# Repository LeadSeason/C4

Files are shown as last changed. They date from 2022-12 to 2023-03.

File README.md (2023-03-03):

<h1 align="center">Connect4 Robot</h1>
<p align="center">Connect 4 robot to play against</p>
<p align="center">
  
</p>

## About
Made with help from [Toni Lipponen](https://github.com/ToniLipponen),
or how I like to call him [Tonnikala](https://github.com/ToniLipponen).  

<p  align="center">
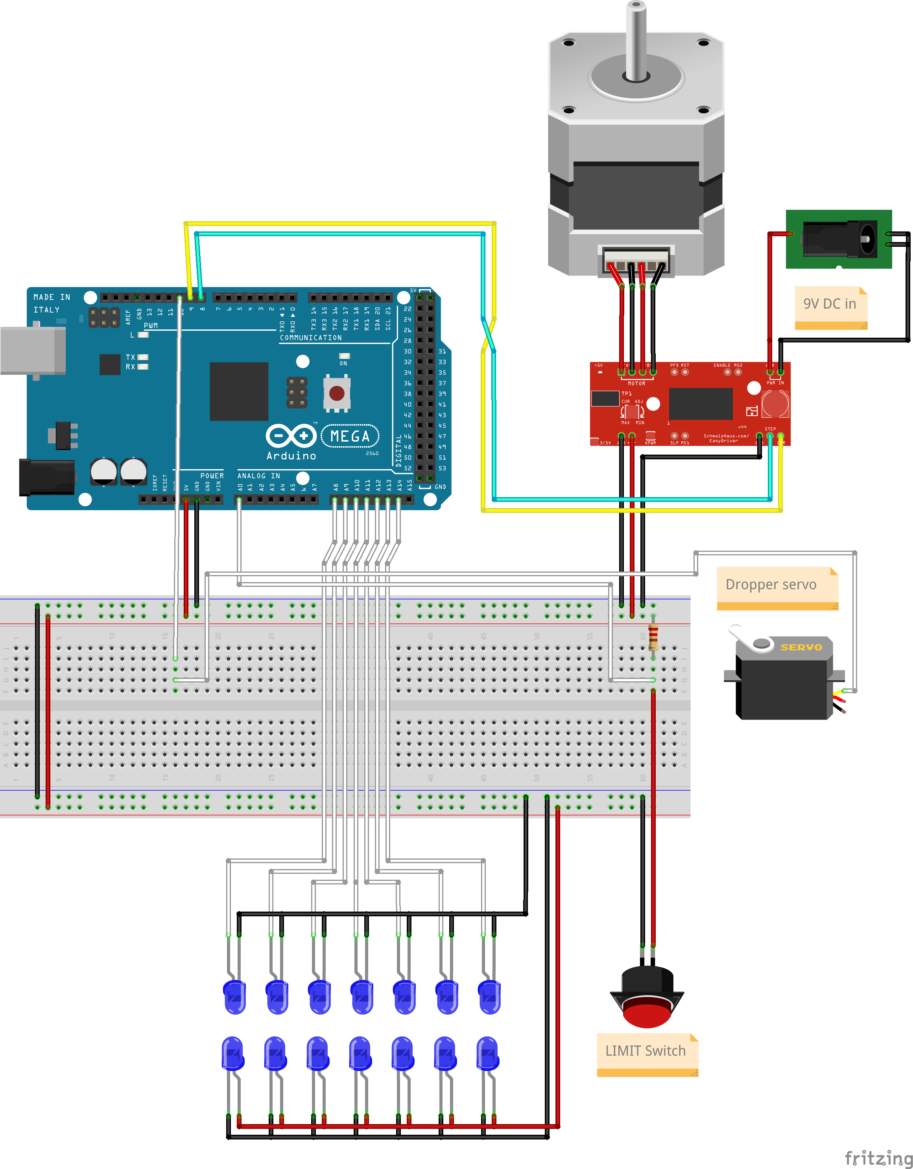
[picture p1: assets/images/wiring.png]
  
</p>

<p  align="center">
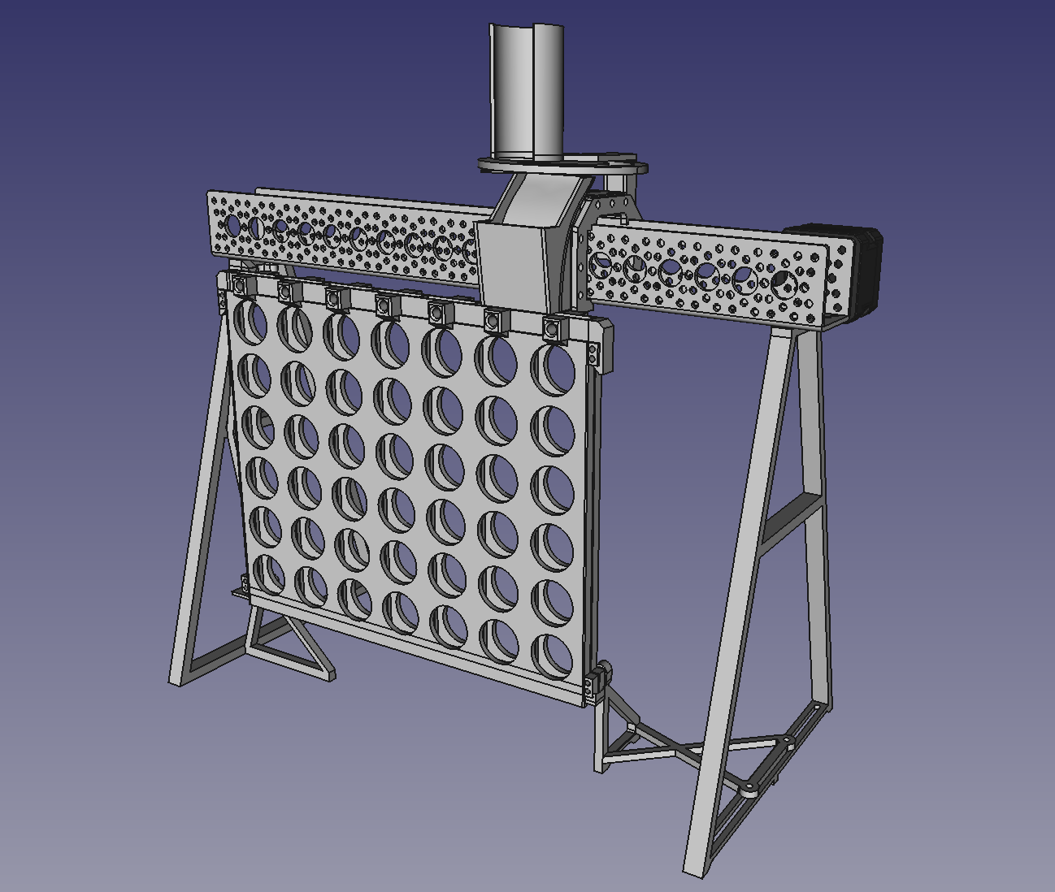
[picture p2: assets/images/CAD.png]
  
</p>

## Problems
- [ ] Algorithm doens't check diagonal
- [ ] Puck Detectors sometimes fails or miss reads
- [ ] Make better mounting system for arduino components

## License
<p align="center">
  <a href="https://www.gnu.org/licenses/gpl-3.0.en.html">GPL-3.0</a>
  <br>
  
</p>

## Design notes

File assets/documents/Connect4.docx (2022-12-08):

# Connect4 bot (C4bot) Order list?

Problems with buying
*1 No stock
*2 Shipping from a non EU state
*3 No Shipping
*4 Website doesn't have https encryption

C-channel
15.94€ https://www.electrokit.com/en/product/actobotics-aluminium-channel-15/
15.88€ https://www.robotshop.com/eu/en/actobotics-aluminum-channel-15.html
9.99$ *2 https://www.servocity.com/12-00-aluminum-channel/
16.79$ *2 https://abra-electronics.com/robotics-actobotics-servocity/structure/channel-standard-aluminum/585458-aluminum-channel-15.html

Channel guides
5.24€ https://www.electrokit.com/en/product/actobotics-channel-slider-b-type-2-pack/
8.98€ *1 https://www.robot-domestici.it/joomla/home/channel-slider-b-pair/formlab
9.90$ *2 *4 http://sun-light.com.sg/index.php?route=product/product&product_id=1192
7.83€ *1 https://www.electan.com/channel-slider-pair-p-4977-en.html
4.49$ *1 *2 https://www.kr4.us/channel-slider-b-pair.html
6.67€ *1 https://sha256systems.eu/Channel-Slider-B-pair/en
4.80€ *1 https://grobotronics.com/channel-slider-b-pair.html?sl=en

Stepper motor
20.22€ https://www.electrokit.com/en/product/stegmotor-1-8-0-14nm-bipolar/
50.81€ *2 https://www.aliexpress.com/item/1005002094944376.html
14.00$ *2 https://www.adafruit.com/product/324
20.79€ *2 https://www.amazon.com/Adafruit-Accessories-Stepper-Motor-NEMA17/dp/B00EYIFW70

Stepper motor driver
8.45€ https://www.electrokit.com/en/product/stepper-motor-driver-drv8825/

Stepper motor driver adapter
(https://www.electrokit.com/en/product/stepper-motor-driver-drv8825/)3.42€ https://www.electrokit.com/en/product/adapterkort-for-stegmotordrivare/

Belt
19.53€ 35” option https://www.servocity.eu/p/3-8-wide-xl-timing-belts/
15.72€ *1 3 x https://www.electrokit.com/en/product/timing-belt-xl-3-8-ft/
12.01$ *2 https://www.studica.com/3-8-inch-timing-belt-1-5p-xl-10-ft
8.99$ *2 https://www.servocity.com/35-175t-3-8-wide-xl-timing/

Belt Pully
10.59€ https://www.electrokit.com/en/product/timing-belt-pulley-xl-10t-5mm/
0.65€ *2 https://www.aliexpress.com/item/1005001734320131.html
12.75$ *2 https://www.ebay.com/itm/392470923917
5.39€ *2 https://www.aliexpress.com/item/4000384463713.html

Limit switch
1.87€ https://www.electrokit.com/en/product/micro-switch-v4-on-on-roller-lever/
4.06€ https://planet-gates.com/products/10pcs-roller-lever-arm-pcb-terminals-micro-limit-normal-open-close-switch-kw12-3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

Price Total list

Part | Vendor | price (€)
C-channel | Electrokit (https://www.electrokit.com/en/product/actobotics-aluminium-channel-15/) | 15.94
Channel guides | electrokit (https://www.electrokit.com/en/product/actobotics-channel-slider-b-type-2-pack/) | 5.24
Stepper motor | electrokit (https://www.electrokit.com/en/product/stegmotor-1-8-0-14nm-bipolar/) | 20.22
Stepper motor driver | electrokit (https://www.electrokit.com/en/product/stepper-motor-driver-drv8825/) | 8.45
Stepper motor driver adapter | electrokit (https://www.electrokit.com/en/product/adapterkort-for-stegmotordrivare/) | 3.42
Belt | servocity (https://www.servocity.eu/p/3-8-wide-xl-timing-belts/) | 19.53
Belt Pully | electrokit (https://www.electrokit.com/en/product/timing-belt-pulley-xl-10t-5mm/) | 10.59
Limit switch | electrokit (https://www.electrokit.com/en/product/micro-switch-v4-on-on-roller-lever/) | 1.87
| | Total:
| | 85.26

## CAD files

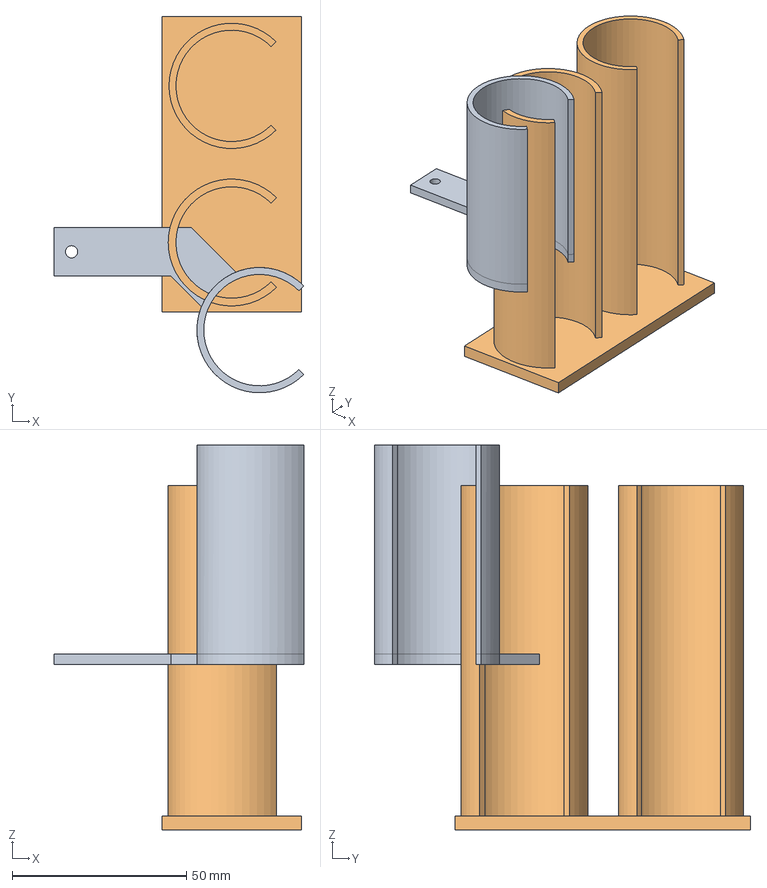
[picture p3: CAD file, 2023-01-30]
assets/freecad/PuckStorage.FCStd
71.7 x 108.2 x 110.6 mm
Funnel
Puck Storage

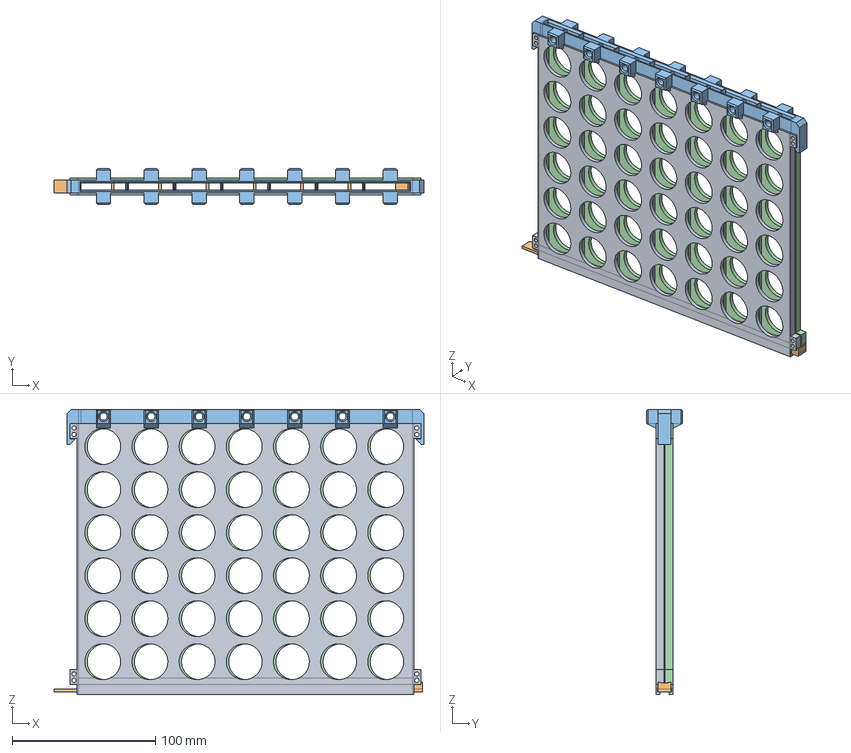
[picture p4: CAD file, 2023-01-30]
assets/freecad/Game-board.FCStd
258.0 x 25.0 x 199.0 mm
Board
hoalder
Detector
Board001

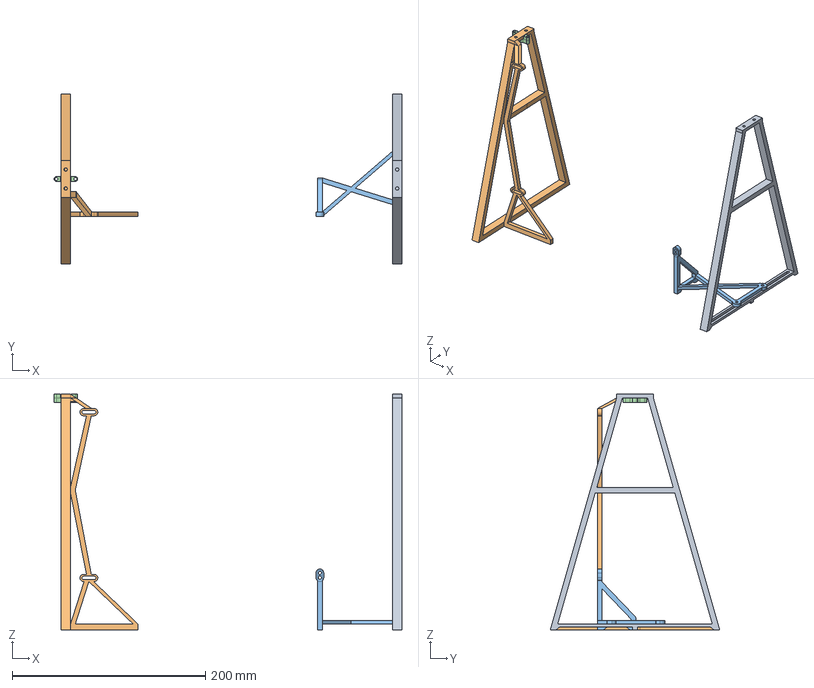
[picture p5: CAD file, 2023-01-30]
assets/freecad/C4-Stand.FCStd
360.0 x 175.4 x 244.1 mm
Stand
Stand Right
SmallBoard Stand
Stand Right.Pach

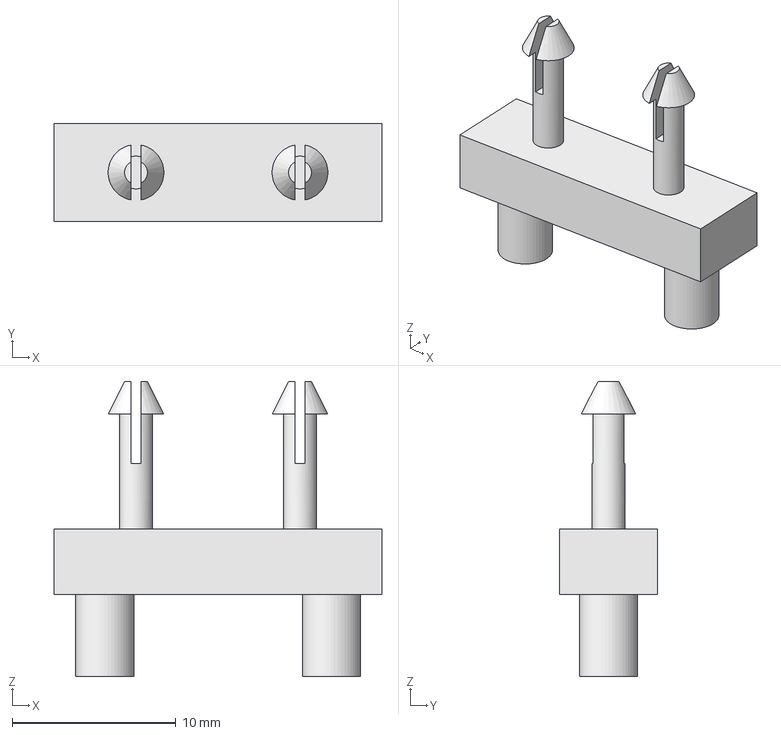
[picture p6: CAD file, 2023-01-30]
assets/freecad/Limit switch.FCStd
20.0 x 6.00 x 18.0 mm

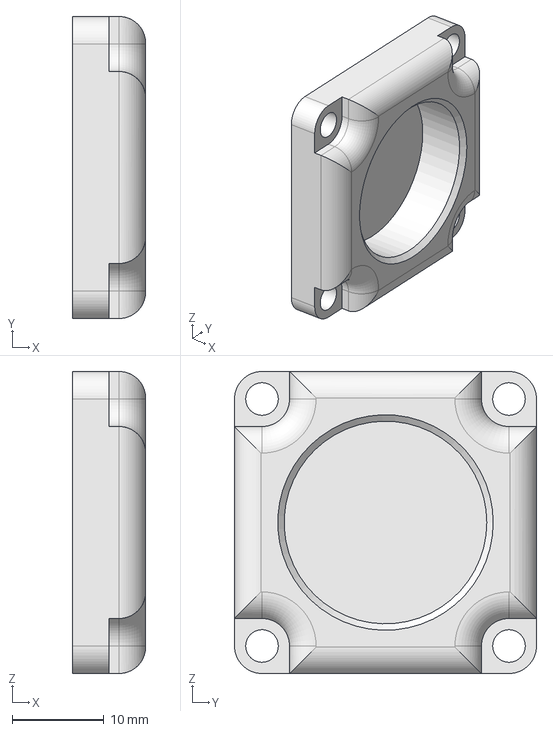
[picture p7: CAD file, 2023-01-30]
assets/freecad/Pulley bearing mount.FCStd
8.00 x 32.9 x 32.9 mm

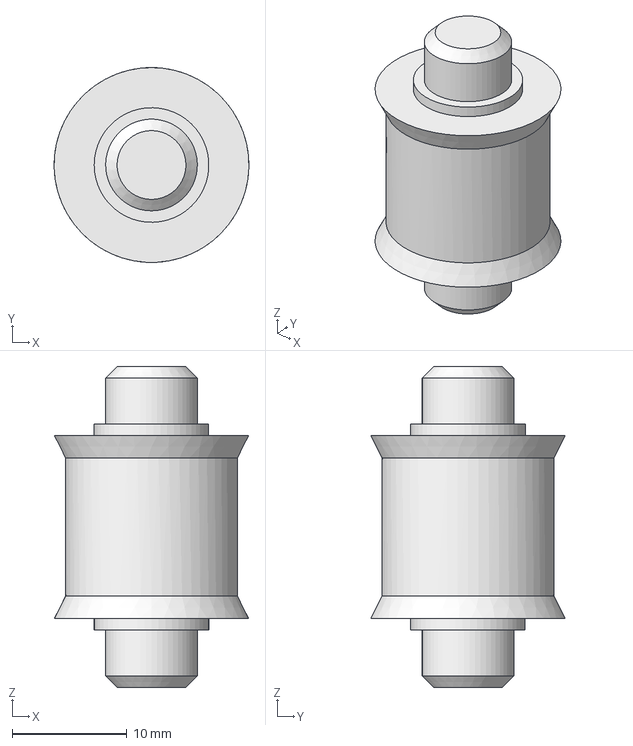
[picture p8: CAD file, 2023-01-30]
assets/freecad/Idlrer pully.FCStd
17.0 x 17.0 x 28.0 mm

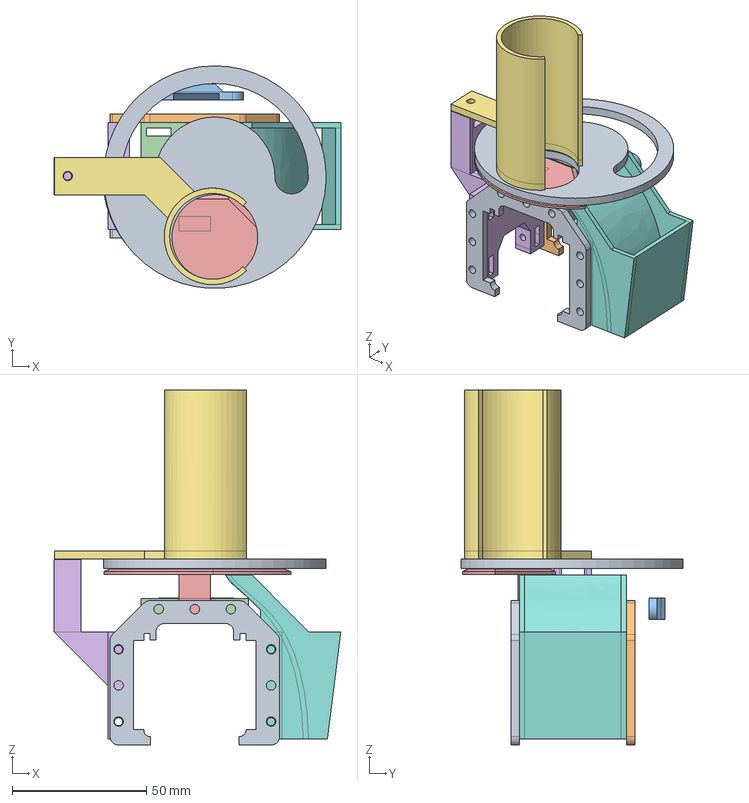
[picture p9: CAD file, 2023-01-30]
assets/freecad/Dropper.FCStd
106.9 x 82.9 x 132.4 mm
Turntable
Channel guide0
Belt Clip
Turntable base
Puck table
Funnel base
Funnel
Drop Funnel
Channel guide1

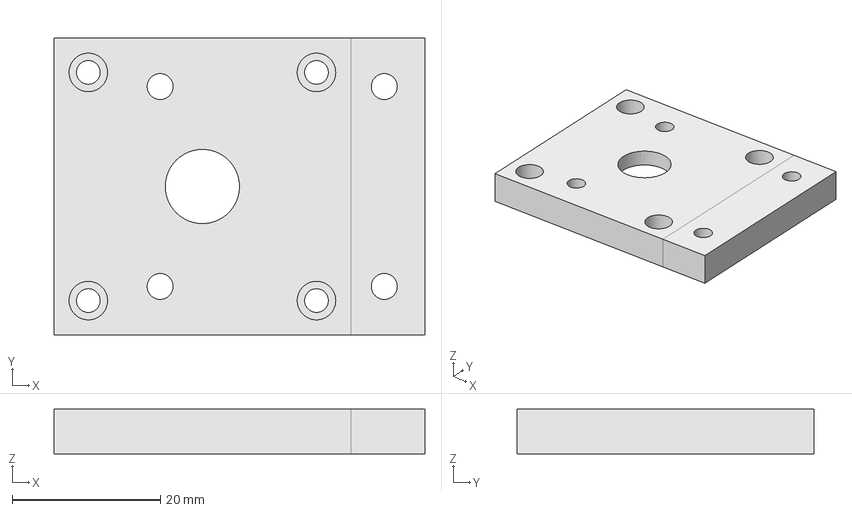
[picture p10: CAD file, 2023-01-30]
assets/freecad/Stepper motor bracket.FCStd
50.0 x 40.0 x 6.00 mm

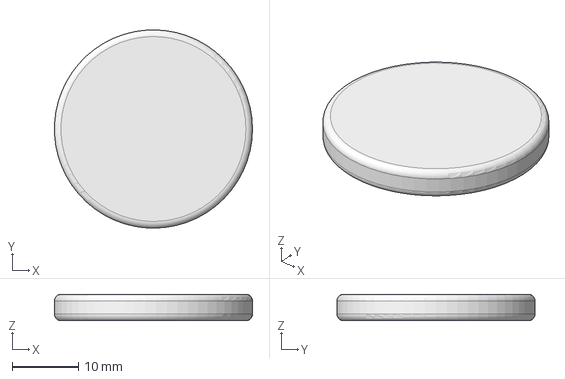
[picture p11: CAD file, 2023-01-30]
assets/freecad/Puck-15mm.FCStd
30.0 x 30.0 x 4.00 mm

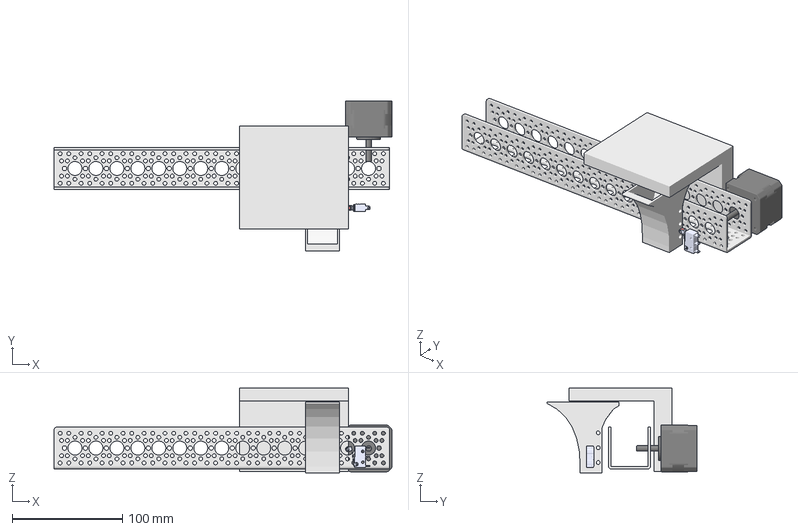
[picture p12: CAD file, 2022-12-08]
assets/freecad/Initial concept CAD.FCStd
307.1 x 136.6 x 77.0 mm
C-chanel
Funnel
Switch_Button
Link
Wheel shaft
Wheel
Plate + Tower
Nema_17_PHB42S34-401A_NEMA_17_PHB42S34-401A v1
Puck1

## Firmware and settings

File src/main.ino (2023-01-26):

#include <Arduino.h>
#include <ezButton.h>
#include <Servo.h>
#include <AccelStepper.h>
#include "dropper.h"
#include "utils.hpp"
#include "sensor.h"
#include "game.h"

// Define stepper motor connections and steps per revolution:
#define PINDIR 8
#define PINSTEP 9
#define PINSERVO 10
#define THRESHOLD 80

const int piceLocations[8] = {0, 7400, 6412, 5400, 4350, 3306, 2254, 1252};
const uint8_t sensorPins[] = {62, 63, 64, 65, 66, 67, 68};
c4Dropper dropper;
Sensor sensors[sizeof(sensorPins)];
Game game;

void setup()
{
    Serial.begin(115200);
    utils::Print("Serial init     ... \033[38;5;2mOK\033[38;5;7m\n");

    utils::Print("Dropper init    ... \n");
    dropper = c4Dropper(PINSTEP, PINDIR);
    utils::Print("Dropper init    ... \033[38;5;2mOK\033[38;5;7m\n");

    utils::Print("Sensors init    ... \n");
    for (int i = 0; i < sizeof(sensorPins); i++)
    {
        pinMode(sensorPins[i], INPUT);
        sensors[i] = Sensor(sensorPins[i], THRESHOLD);
        utils::Print("\033[38;5;7mSensor (%d)\033[38;5;4m %d \033[38;5;%dm%d\033[38;5;7m, (%d - %d - %d)\n",
        i, sensors[i].getNewValue(), sensors[i].getState(), sensors[i].getState(), sensors[i].getMinValue(), sensors[i].getValue(), sensors[i].getMaxValue());
    }
    utils::Print("Sensors init    ... \033[38;5;2mOK\033[38;5;7m\n");

    utils::Print("Game logic init ... ");
    game = Game();
    utils::Print("\033[38;5;2mOK\033[38;5;7m\n");
    game.displayBoard();
}

void loop()
{
    unsigned int colunm = 0;
    for (Sensor& sensor : sensors)
    {
        int sens_loop = sensor.sensorLoop();
        if (sensor.getState())
        {
            // clear terminal.
            // Print info about puck detection results.
            utils::Print("%d \033[38;5;7mLed (%d)\033[38;5;4m %d \033[38;5;%dm%d\033[38;5;7m, (%d - %d - %d)\n",
            sens_loop, colunm, sensor.getNewValue(), sensor.getState(), sensor.getState(), sensor.getMinValue(), sensor.getValue(), sensor.getMaxValue());

            game.dropPiece(colunm + 1);
            utils::Print("Gameover State: %d\n", game.checkWinners());
            game.displayBoard();
            checkGameOver(game.checkWinners());
            utils::Print("\n");

            int aiMove = game.aiPlayMove();

            while (sensor.getStateLoop()) {}

            utils::Print("🤔Ai Playing move: %d. Dropping\n", aiMove);
            utils::Print("Gameover State: %d\n", game.checkWinners());
            game.displayBoard();

            dropper.dropPice(piceLocations[aiMove]);

            checkGameOver(game.checkWinners());
            utils::Print("\n");
        }
        colunm++;
    }
    delay(20);
}

void checkGameOver(int gameover)
{
	if (gameover != 0)
	{
		if (gameover == -1)
		{
			utils::Print("No body won Sad🙁\n");
		}
		else if (gameover == 1)
		{
			utils::Print("Orage Player Won🎉\n");
		}
		else if (gameover == 2)
		{
			utils::Print("Yellow Player Won🎉\n");
		}
		else
		{
			utils::Print("Player %d Won🎉\n", gameover);
		}
		utils::Print("\n");

        utils::Print("Gameover. Clear board and press reset to restart game\n");
        while (true) {}
	}
}

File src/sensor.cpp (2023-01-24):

#include "sensor.h"

Sensor::Sensor()
{

}

Sensor::Sensor(uint8_t sensorPin, int pinThreshold)
{
    pin = sensorPin;
    threshold = pinThreshold;

    pinMode(pin, INPUT);

    previousValue = analogRead(pin);
    for (size_t i = 1; i < 20; i++)
    {
        previousValue = ((previousValue * (i - 1)) + analogRead(pin)) / i;
        delay(20);
    }

    previousValueMax = previousValue + (threshold >> 1);
    previousValueMin = previousValue - (threshold >> 1);
}

int Sensor::sensorLoop()
{
    sensorNewValue = analogRead(pin);
    if (sensorNewValue >= previousValueMax)
    {
        state = false;
        return 1;
    } 
    if (sensorNewValue <= previousValueMin)
    {
        state = true;
        return -1;
    }
    state = false;
    return 0;
}

bool Sensor::getStateLoop()
{
    sensorLoop();
    return state;
}

bool Sensor::getState()
{
    return state;
}

int Sensor::getNewValue()
{
    return sensorNewValue;
}

int Sensor::getValue()
{
    return previousValue;
}

int Sensor::getCurrentValue()
{
    return analogRead(pin);
}

int Sensor::getMaxValue()
{
    return previousValueMax;
}

int Sensor::getMinValue()
{
    return previousValueMin;
}

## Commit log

2023-01-26 Fixed Minmax not working
    [main.ino]
2023-01-26 Moved documents
    [PreCad C4.FCStd]
2023-01-26 Renamed folders
    [PreCad C4.FCStd]
2023-01-30 Added images of the wiring
    [wiring-sketch.fzz]
2023-01-30 Added CAD files
    [C4-Stand.FCStd, Dropper.FCStd, Game-board.FCStd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]
2023-01-30 Added PuckStorage CAD
    [PuckStorage.FCStd]
2023-01-30 Updated wiring-sketch.fzz
    [wiring-sketch.fzz]
